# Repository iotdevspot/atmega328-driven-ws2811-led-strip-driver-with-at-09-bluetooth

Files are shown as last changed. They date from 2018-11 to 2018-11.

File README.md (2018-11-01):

# atmega328-driven-ws2811-led-strip-driver-with-at-09-bluetooth

This project contains a WS2811 LED strip driver hardware with 2 different communication modes with appropirate Arduino sketches for each. 

The two communication modes are the following:

* **WiFi** supported by an ESP8266 Wifi module
* **BLE** supported by an AT-09 Bluetooth module

## Bluetooth version

I've used the following AT commands in order to change the behaviour (changing name, changing pin and the baud rate) of the BLE module and I've done them before attaching it to the board. 

* AT+NAME
* AT+PIN
* AT+BAUD

After this procedure the module is ready to be assembled.

**Useable commands and their descriptions in the following format: "command" - description**
* "A" - Red color mode
* "B" - Green color mode
* "C" - Blue color mode
* "D" - Rainbow 1 mode
* "E" - Rainbow 2 mode
* "F" - Custom color mode
* "G,<color red 0..255>,<color green 0..255>,<color blue 0..255>" - Color setting command
* "H" - Relay on command
* "I" - Relay off command

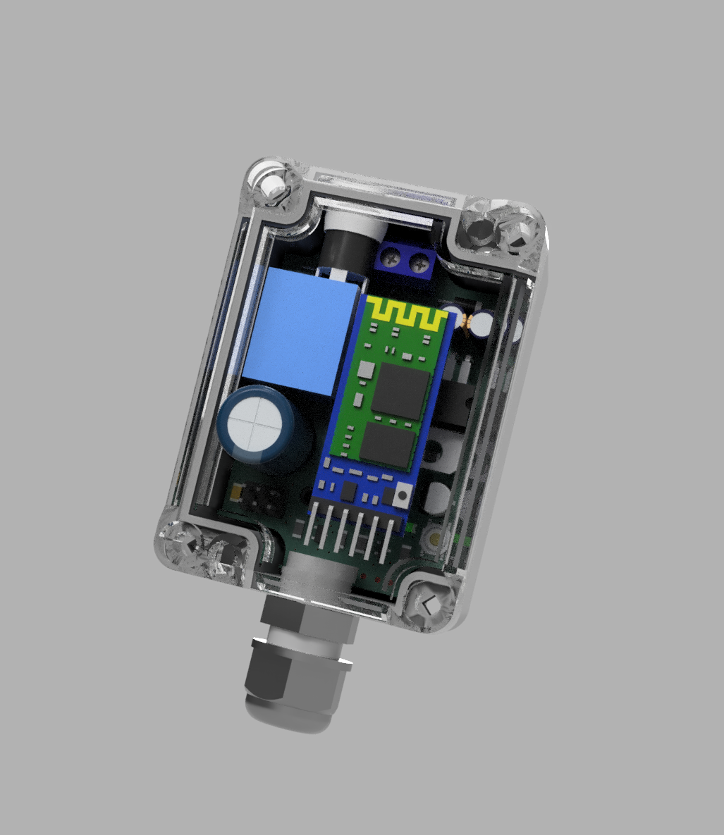
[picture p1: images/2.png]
bluetooth version


## WiFi version

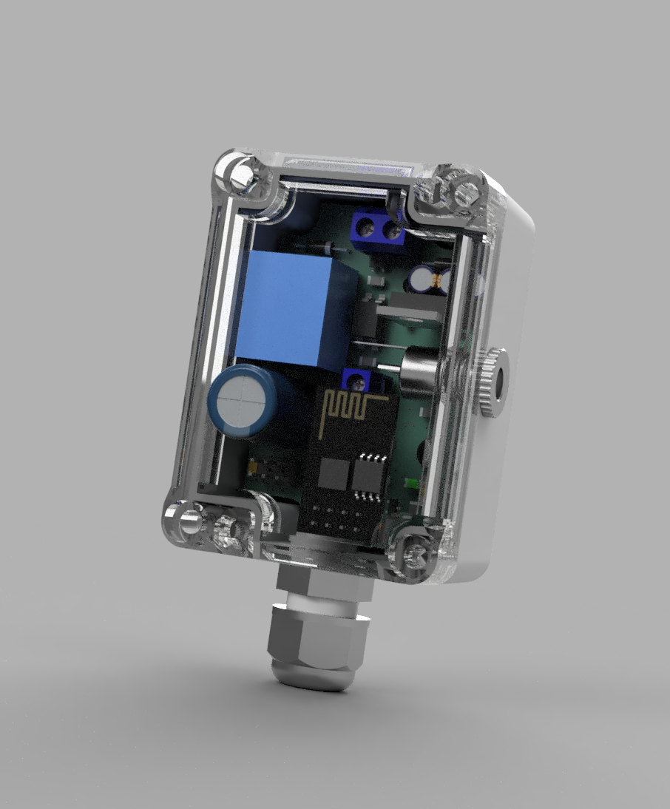
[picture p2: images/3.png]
wifi version


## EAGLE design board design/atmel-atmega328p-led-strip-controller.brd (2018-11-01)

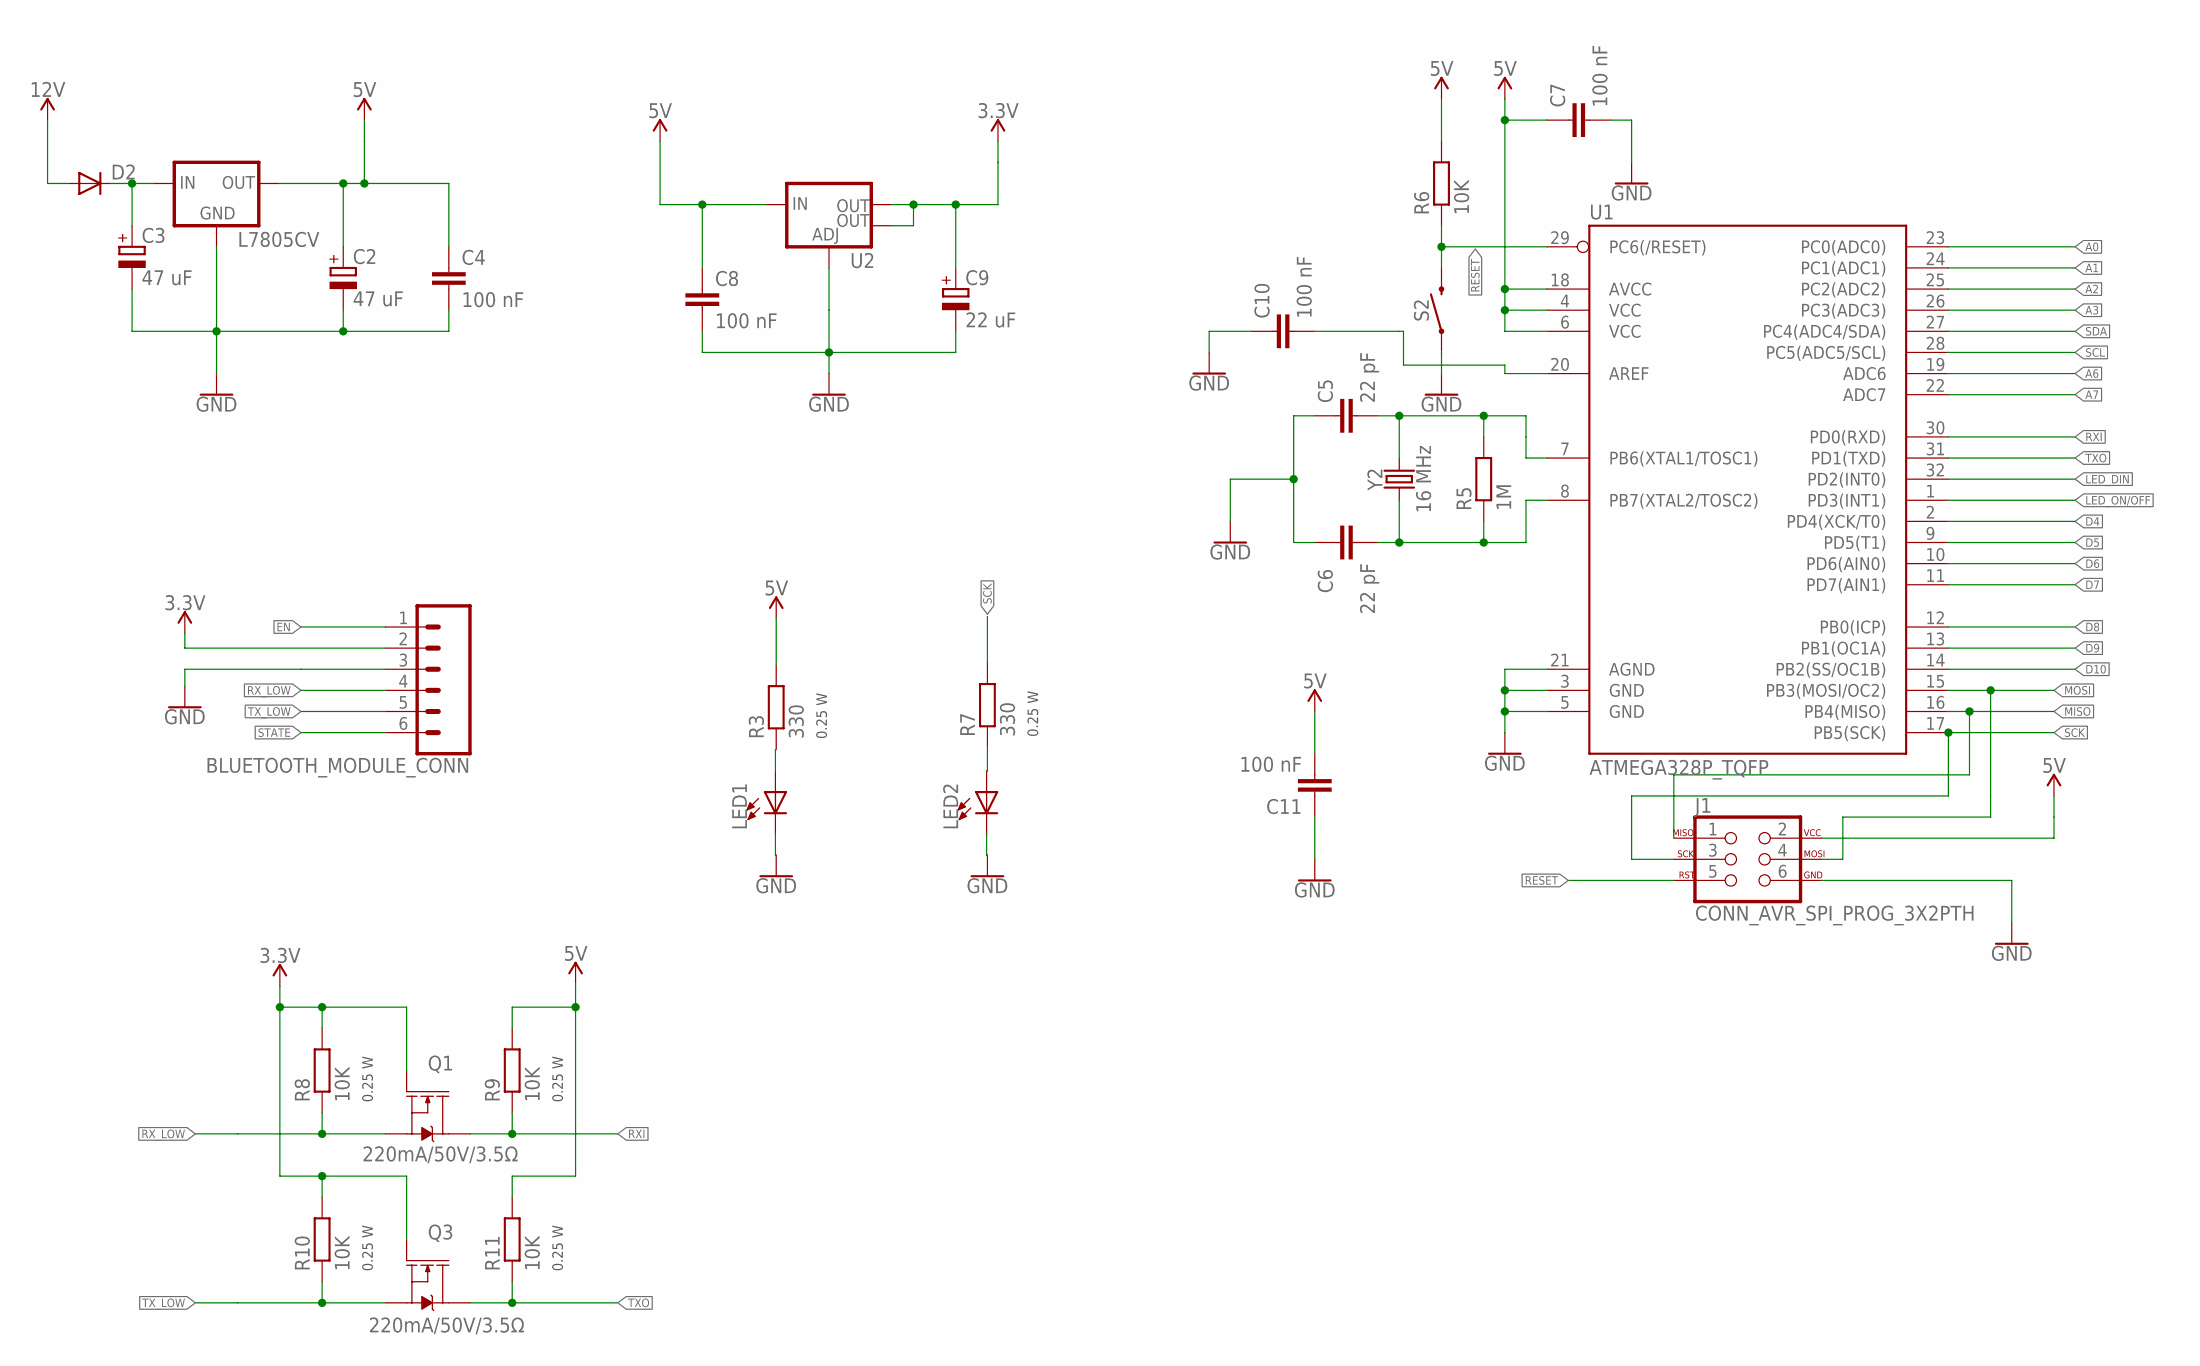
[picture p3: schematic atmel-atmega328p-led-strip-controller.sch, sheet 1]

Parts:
BLUETOOTH_MODULE_CONN: CONN_06SILK_FEMALE_PTH; 1X06
C2, C3: 47 uF; E2,5-5
C4, C7, C8, C10, C11: 100 nF; C1206I-C3216M
C5, C6: 22 pF; C1206I-C3216M
C9: 22 uF; 153CLV-0505
D2: DIODED-10; D-10
J1: CONN_AVR_SPI_PROG_3X2PTH; 2X3_S
L7805CV: V_REG_78XX_STANDING; 78XXS
LED1, LED2: LEDCHIPLED_1206_G; LED_1206_G
Q1, Q3: 220mA/50V/3.5Ω; SOT23-3
R3, R7: 330; R1206
R5: 1M; R1206
R6, R8, R9, R10, R11: 10K; R1206
S2: INPUT_MOMENTARY_SWITCH_SPST-SMD-5.2MM; TACTILE_SWITCH_SMD_5.2MM
U1: ATMEGA328P_TQFP; TQFP32-08
U2: V_REG_LM1117SOT223; SOT223
Y2: 16 MHz; CRYSTAL-SMD-3.2X2.5MM

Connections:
3.3V: BLUETOOTH_MODULE_CONN.2, C9.+, Q1.1 (G), Q3.1 (G), R8.2, R10.2, U2.2 (OUT), U2.4 (OUT)
5V: C2.+, C4.1, C7.1, C8.1, C11.2, J1.2, L7805CV.OUT, R3.2, R6.2, R9.2, R11.2, U1.4 (VCC), U1.6 (VCC), U1.18 (AVCC), U2.3 (IN); also elsewhere on the board
12V: D2.A; also elsewhere on the board
A0: U1.23 (PC0(ADC0))
A1: U1.24 (PC1(ADC1))
A2: U1.25 (PC2(ADC2))
A3: U1.26 (PC3(ADC3))
A6: U1.19 (ADC6)
A7: U1.22 (ADC7)
D4: U1.2 (PD4(XCK/T0))
D5: U1.9 (PD5(T1))
D6: U1.10 (PD6(AIN0))
D7: U1.11 (PD7(AIN1))
D8: U1.12 (PB0(ICP))
D9: U1.13 (PB1(OC1A))
D10: U1.14 (PB2(SS/OC1B))
EN: BLUETOOTH_MODULE_CONN.1
GND: BLUETOOTH_MODULE_CONN.3, C2.-, C3.-, C4.2, C5.1, C6.1, C7.2, C8.2, C9.-, C10.1, C11.1, J1.6, L7805CV.GND, LED1.C, LED2.C, S2.1, U1.3 (GND), U1.5 (GND), U1.21 (AGND), U2.1 (ADJ); also elsewhere on the board
LED_DIN: U1.32 (PD2(INT0)); also elsewhere on the board
LED_ON/OFF: U1.1 (PD3(INT1)); also elsewhere on the board
MISO: J1.1, U1.16 (PB4(MISO))
MOSI: J1.4, U1.15 (PB3(MOSI/OC2))
unnamed: C5.2, R5.2, U1.7 (PB6(XTAL1/TOSC1)), Y2.3 (2)
unnamed: C6.2, R5.1, U1.8 (PB7(XTAL2/TOSC2)), Y2.1
unnamed: C10.2, U1.20 (AREF)
unnamed: LED1.A, R3.1
unnamed: C3.+, D2.C, L7805CV.IN
unnamed: LED2.A, R7.1
RESET: J1.5, R6.1, S2.3 (2), U1.29 (PC6(/RESET))
RXI: Q1.3 (D), R9.1, U1.30 (PD0(RXD))
RX_LOW: BLUETOOTH_MODULE_CONN.4, Q1.2 (S), R8.1
SCK: J1.3, R7.2, U1.17 (PB5(SCK))
SCL: U1.28 (PC5(ADC5/SCL))
SDA: U1.27 (PC4(ADC4/SDA))
STATE: BLUETOOTH_MODULE_CONN.6
TXO: Q3.3 (D), R11.1, U1.31 (PD1(TXD))
TX_LOW: BLUETOOTH_MODULE_CONN.5, Q3.2 (S), R10.1

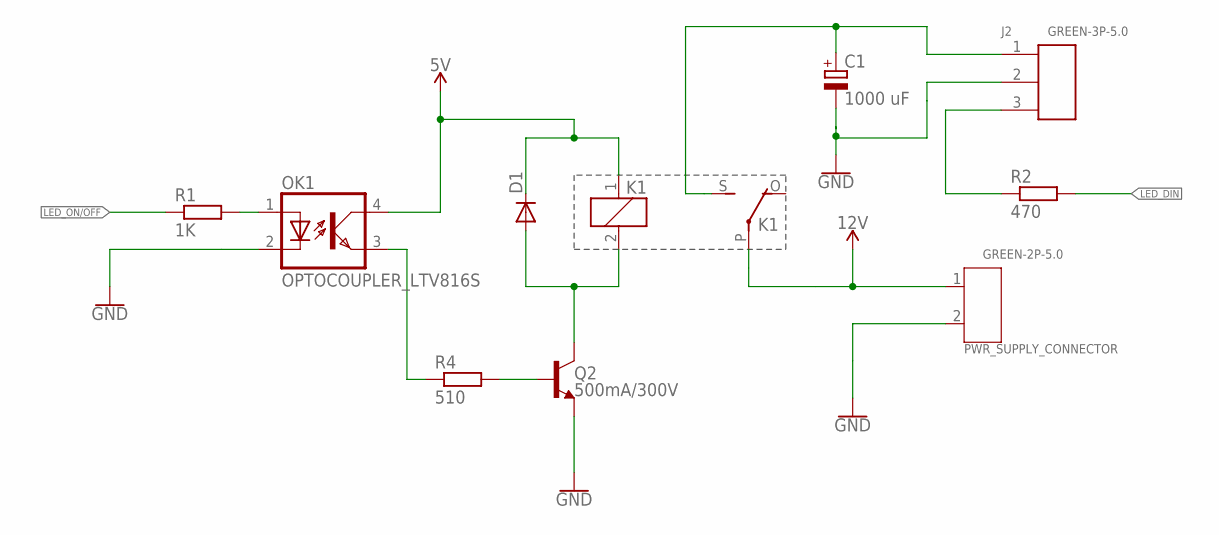
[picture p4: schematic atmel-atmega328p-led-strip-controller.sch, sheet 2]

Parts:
C1: 1000 uF; E5-13
D1: DIODED-10; D-10
J2: GREEN-3P-5.0; H3-5.0-15.5X8.0MM
K1: RELAY_ZF112; ZF112
OK1: OPTOCOUPLER_LTV816S; DIL4-SMD
PWR_SUPPLY_CONNECTOR: GREEN-2P-5.0; H2-5.0-10.5X8.0MM
Q2: 500mA/300V; SOT23-3
R1: 1K; R1206
R2: 470; R1206
R4: 510; R1206

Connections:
5V: D1.C, K1.1, OK1.4 (COL); also elsewhere on the board
12V: K1.P, PWR_SUPPLY_CONNECTOR.1; also elsewhere on the board
GND: C1.-, J2.2, OK1.2 (C), PWR_SUPPLY_CONNECTOR.2, Q2.2 (E); also elsewhere on the board
LED_DIN: R2.2; also elsewhere on the board
LED_ON/OFF: R1.1; also elsewhere on the board
unnamed: J2.3, R2.1
unnamed: D1.A, K1.2, Q2.3 (C)
unnamed: OK1.1 (A), R1.2
unnamed: Q2.1 (B), R4.2
unnamed: OK1.3 (EMIT), R4.1
unnamed: C1.+, J2.1, K1.S

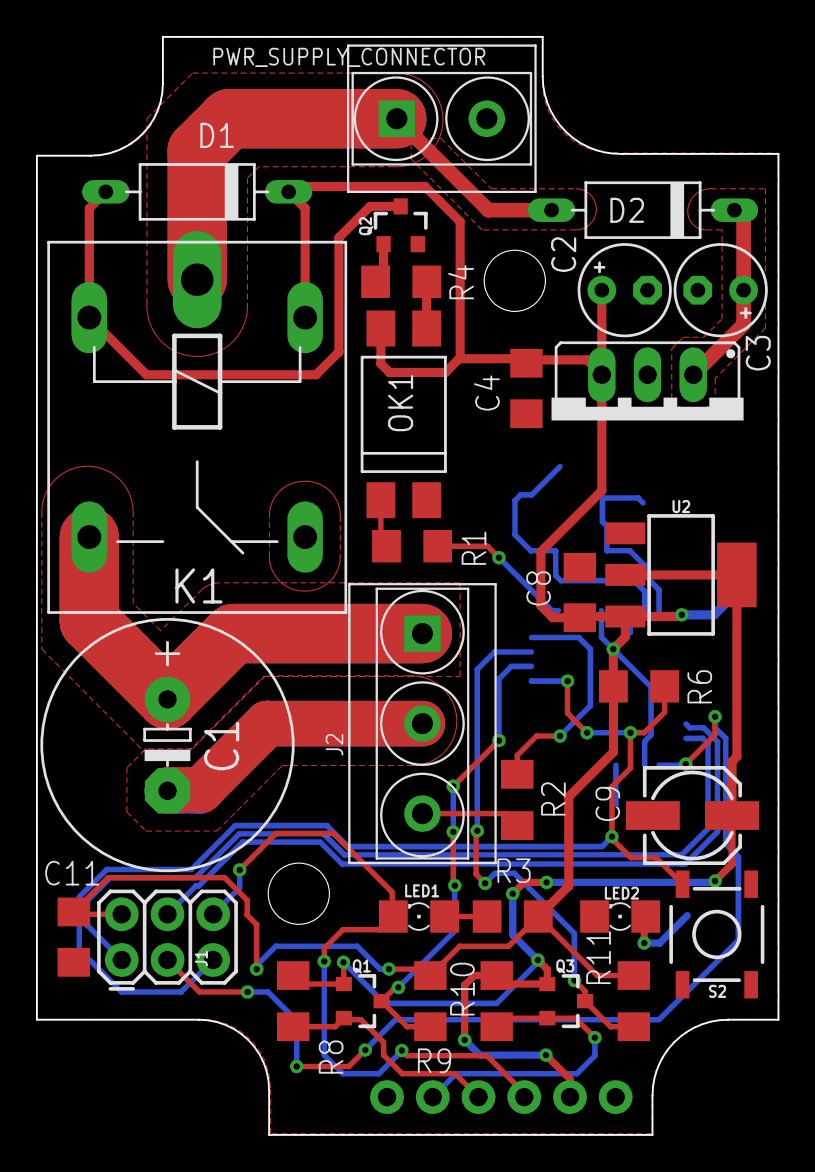
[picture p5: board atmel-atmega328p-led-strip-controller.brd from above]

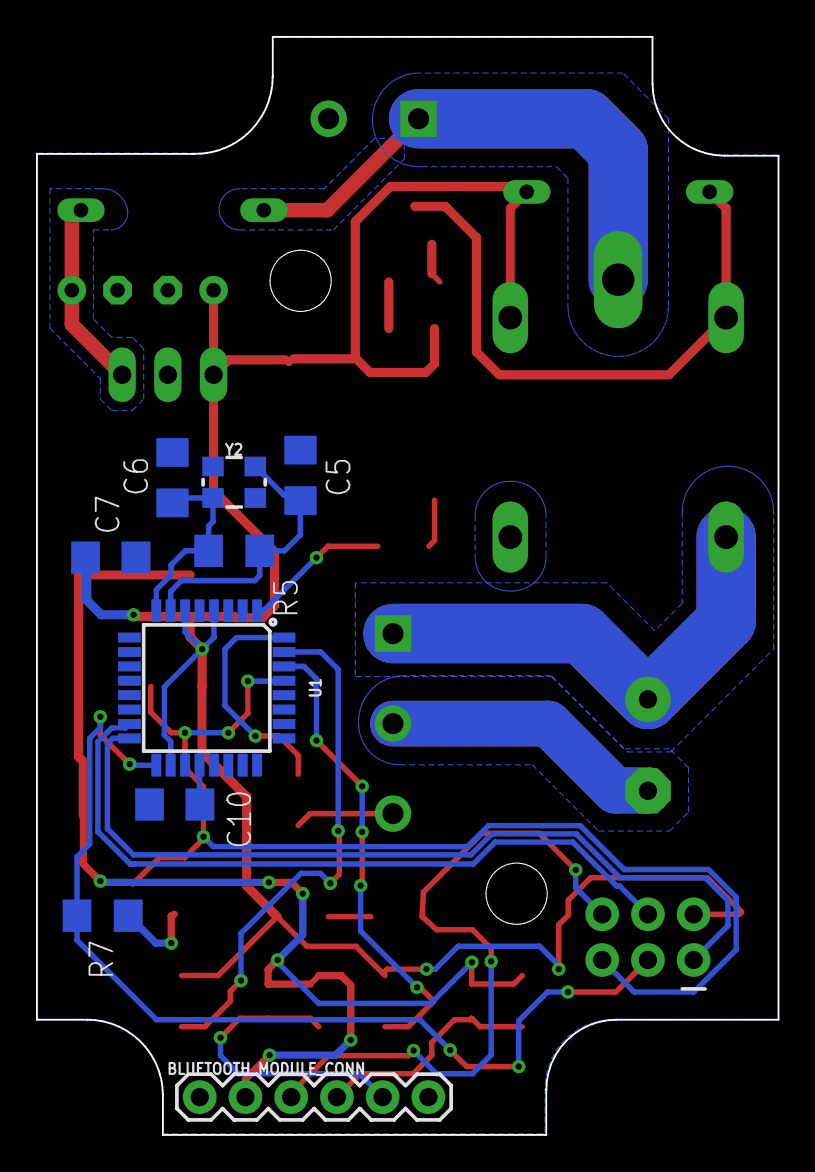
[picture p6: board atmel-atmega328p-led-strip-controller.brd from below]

Board: 2 copper layers, 41.2 x 61.0 mm, 40 parts (9 on the bottom side), 26 nets.

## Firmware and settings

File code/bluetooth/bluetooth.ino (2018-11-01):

#include <Adafruit_NeoPixel.h>

#ifdef __AVR__
  #include <avr/power.h>
#endif

const int PIXEL_COUNT = 75;
const int LED_STRIP_PIN = 2;
const int USER_LED_PIN = 13;
const int RELAY_PIN = 3;

char state = 'A';
char inputCommand;
byte r, g, b;

Adafruit_NeoPixel strip = Adafruit_NeoPixel(PIXEL_COUNT, LED_STRIP_PIN, NEO_GRB + NEO_KHZ800);
 

void setup() {
  #if defined (__AVR_ATtiny85__)
    if (F_CPU == 16000000) clock_prescale_set(clock_div_1);
  #endif
  
  pinMode(USER_LED_PIN, OUTPUT);
  
  strip.begin();
  strip.show();

  Serial.begin(115200); //modulhoz szükséges baud rate
}

void loop() {
  
  while(Serial.available())
  {
    inputCommand = Serial.read();
    //Serial1.write("Bemenet jött"+inputCommand);
    if(inputCommand <= 'F' && inputCommand >= 'A')
    {
      state = inputCommand;
      Serial.write(inputCommand);
      Serial.flush();
    }
    else
    {
        switch(inputCommand)
        {
          case 'G':
            String message;
            while(Serial.available())
            {
                message+=char(Serial.read());
            }
            int av = message.indexOf("G");
            int bv = message.lastIndexOf("G");
            r = message.substring(0,av).toInt();
            g = message.substring(av+1,bv).toInt();
            b = message.substring(bv+1).toInt();
            state = 'F';
            Serial.print("G");
            Serial.print(r);
            Serial.print(g);
            Serial.print(b);
            Serial.flush();
          break;
          case 'H':
            digitalWrite(RELAY_PIN, HIGH);
            Serial.write('H');
            Serial.flush();
          break;
          case 'I':
            digitalWrite(RELAY_PIN, LOW);
            Serial.write('I');
            Serial.flush();
          break;
          default:
            
          break;
        }
    }
  }
  startShow(state);
}


void startShow(int i) {
  //átmenet lehetne a váltásnál
  switch(i){
    case 'A': 
      colorWipe(strip.Color(255, 0, 0), 10);  // Red
      break;
    case 'B': 
      colorWipe(strip.Color(0, 255, 0), 10);  // Green
      break;
    case 'C': 
      colorWipe(strip.Color(0, 0, 255), 10);  // Blue
      break;
    case 'D': 
      rainbow(10);
      break;
    case 'E': 
      rainbowCycle(10);
      break;
    case 'F': 
      colorWipe(strip.Color(r, g, b), 10);  // Custom color
      break;
  }
}

// Fill the dots one after the other with a color
void colorWipe(uint32_t c, uint8_t wait) {
  for(uint16_t i=0; i<strip.numPixels(); i++) {
    strip.setPixelColor(i, c);
    strip.show();
    delay(wait);
  }
}

void rainbow(uint8_t wait) {
  uint16_t i, j;

  for(j=0; j<256; j++) {
    for(i=0; i<strip.numPixels(); i++) {
      strip.setPixelColor(i, Wheel((i+j) & 255));
    }
    strip.show();
    delay(wait);
  }
}

// Slightly different, this makes the rainbow equally distributed throughout
void rainbowCycle(uint8_t wait) {
  uint16_t i, j;

  for(j=0; j<256*5; j++) { // 5 cycles of all colors on wheel
    for(i=0; i< strip.numPixels(); i++) {
      strip.setPixelColor(i, Wheel(((i * 256 / strip.numPixels()) + j) & 255));
    }
    strip.show();
    delay(wait);
  }
}

// Input a value 0 to 255 to get a color value.
// The colours are a transition r - g - b - back to r.
uint32_t Wheel(byte WheelPos) {
  WheelPos = 255 - WheelPos;
  if(WheelPos < 85) {
    return strip.Color(255 - WheelPos * 3, 0, WheelPos * 3);
  }
  if(WheelPos < 170) {
    WheelPos -= 85;
    return strip.Color(0, WheelPos * 3, 255 - WheelPos * 3);
  }
  WheelPos -= 170;
  return strip.Color(WheelPos * 3, 255 - WheelPos * 3, 0);
}

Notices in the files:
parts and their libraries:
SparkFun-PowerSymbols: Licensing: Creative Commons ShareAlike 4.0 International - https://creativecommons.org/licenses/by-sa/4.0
